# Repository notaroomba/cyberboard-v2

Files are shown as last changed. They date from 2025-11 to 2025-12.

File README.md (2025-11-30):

<h1 align="center">
  <br>
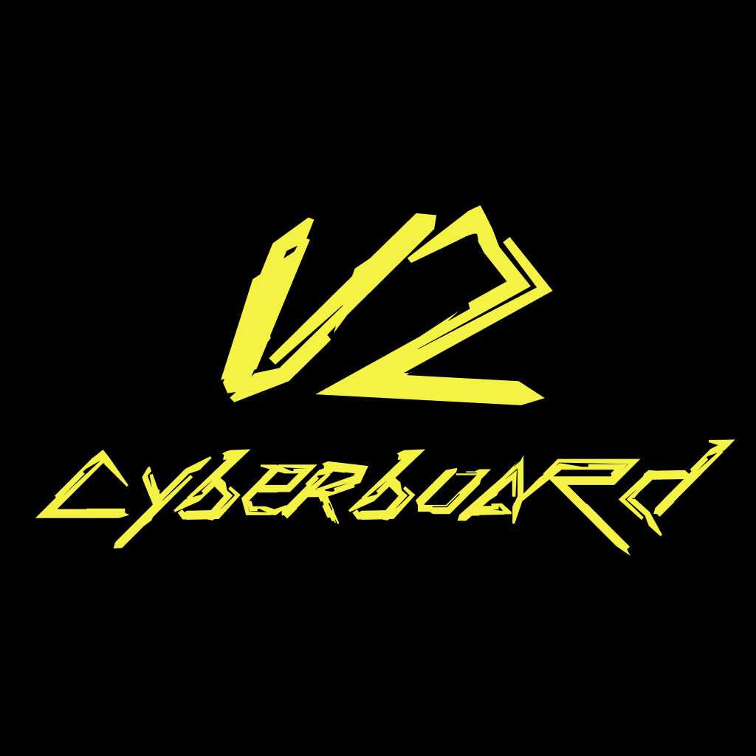
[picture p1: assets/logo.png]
Cyberboard V2
  
  <br>
  Cyberboard V2
  <br>
</h1>

<h4 align="center">
A Raspberry Pi Pico-sized STM32 development board with Bluetooth, battery support, IMU and a barometer!
</h4>

<div align="center">




</div>

<p align="center">
  <a href="#key-features">Key Features</a> •
  <a href="#pcb">PCB</a> •
  <a href="#credits">Credits</a> •
  <a href="#license">License</a>
</p>

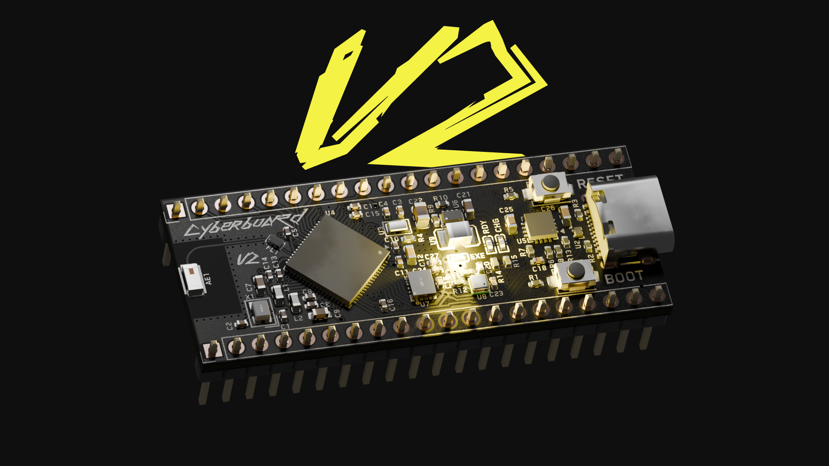
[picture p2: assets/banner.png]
Cyberboard Banner


## Key Features

- **STM32WB55CG** microcontroller with Bluetooth support
- **Raspberry Pi Pico form factor** for compatibility
- **IMU and Barometer** - ICM-42688 (6-axis) and BMP580 pressure sensor for environmental/motion sensing
- **Battery charging** with BQ24072RGTR IC and JST connector for 1S LiPo
- **Buck-Boost converter** (TPS631000) for efficient power management
- **Multiple Status LEDs** for visual feedback
- **USB-C** connectivity
- **Ceramic Bluetooth antenna** with impedance matching
- **SWD test points** on the bottom for easy programming
- **4-layer PCB** design with optimized RF layout and routing
- **Panelized design** for cost-effective manufacturing

## PCB

Designed in KiCad with attention to RF design, power management, and sensor integration. The board features a 4-layer stackup (SIG/GND/PWR/SIG) with optimized routing for the Bluetooth antenna and sensitive analog signals.

### Features

- Efficient antenna routing with impedance matching
- Optimized sensor placement (IMU and Barometer) away from RF components
- SPI interface for IMU (ICM-42688) and I2C interface for Barometer (BMP580)
- Improved power delivery with optimized buck-boost converter

### Schematic

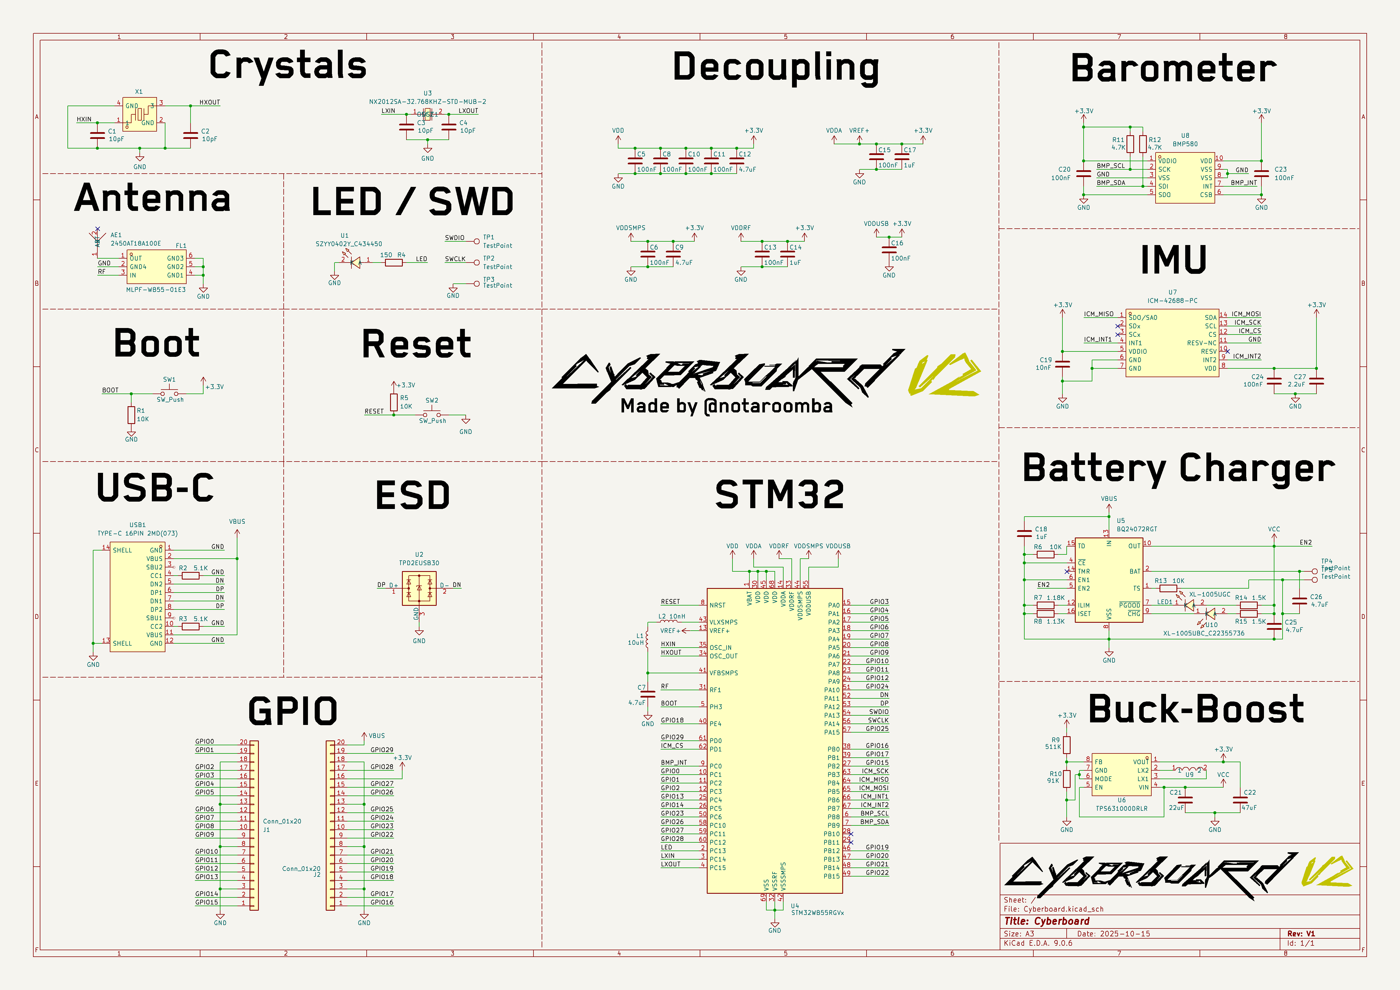
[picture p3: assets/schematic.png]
Schematic


### PCB Layers

The 4-layer stackup (SIG/GND/PWR/SIG) provides optimal signal integrity and power distribution:

**Layer 1 (Signal):**
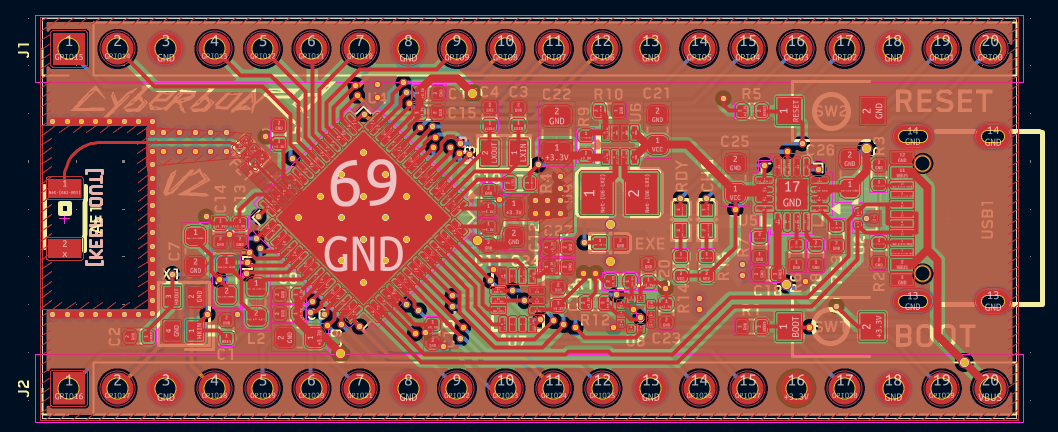
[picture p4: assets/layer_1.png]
PCB Layer 1


**Layer 2 (Ground):**
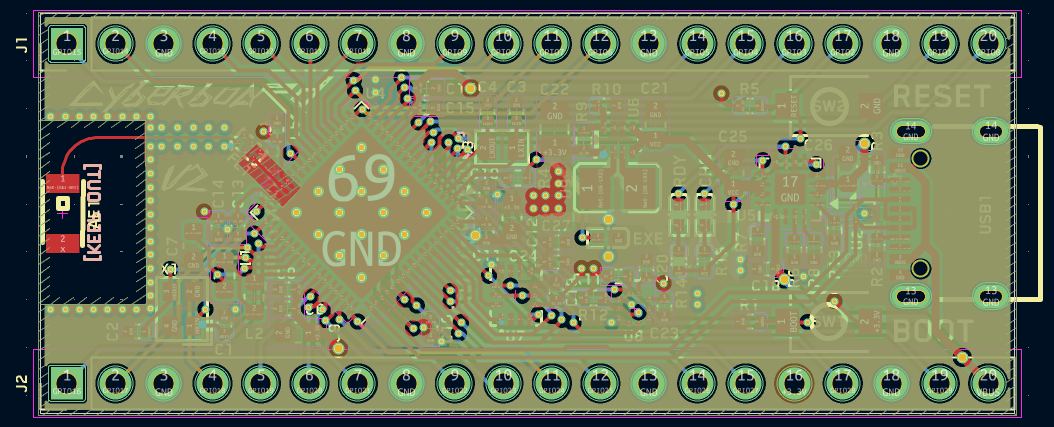
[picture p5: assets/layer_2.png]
PCB Layer 2


**Layer 3 (Power):**
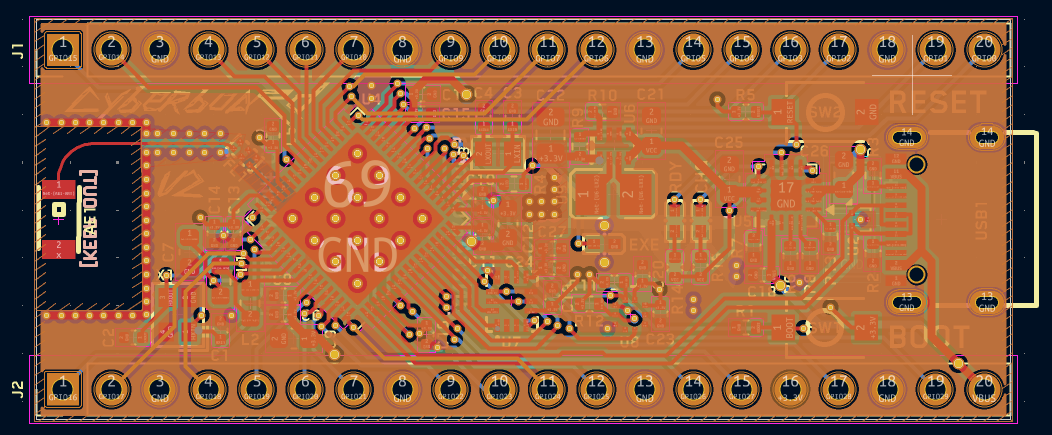
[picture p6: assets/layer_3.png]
PCB Layer 3


**Layer 4 (Signal):**
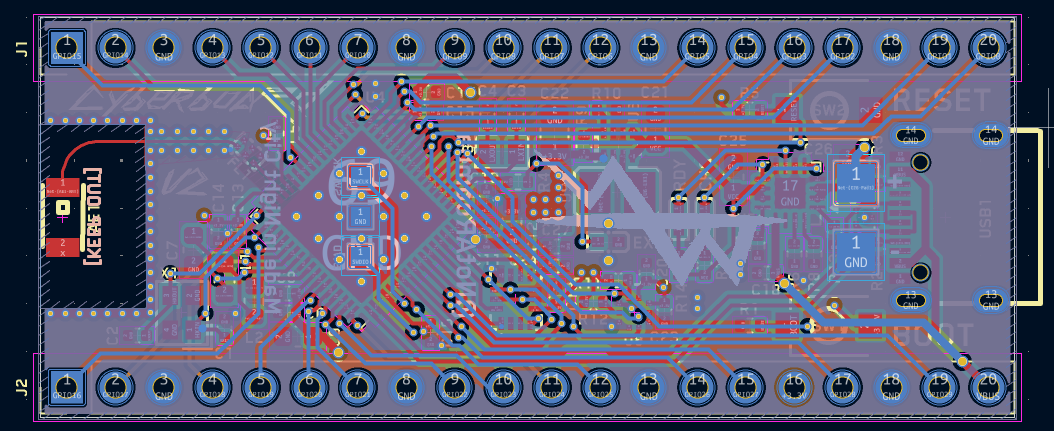
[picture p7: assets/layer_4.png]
PCB Layer 4


**Front:**
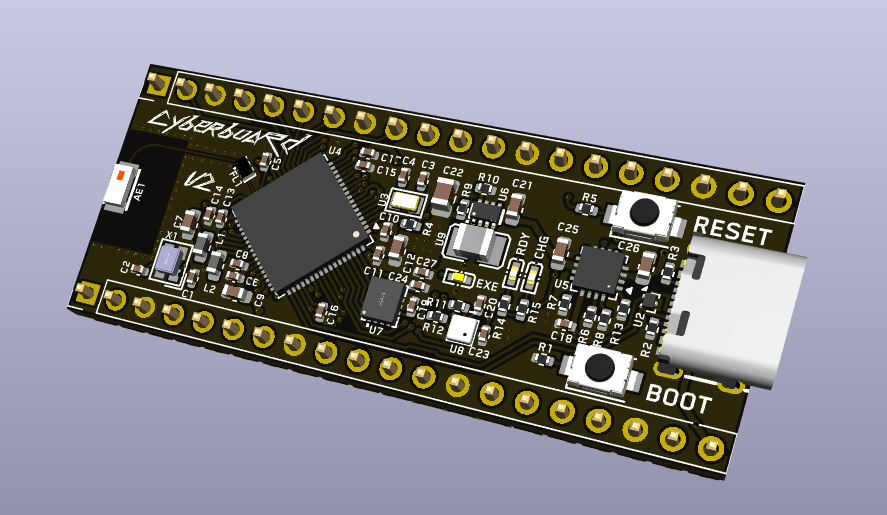
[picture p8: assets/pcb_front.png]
PCB Front


**Back:**
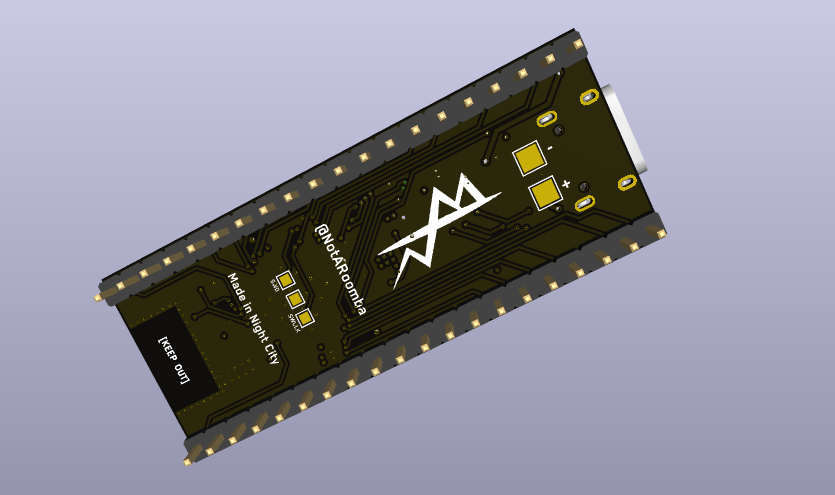
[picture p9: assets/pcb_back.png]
PCB Back


### JLCPCB Order

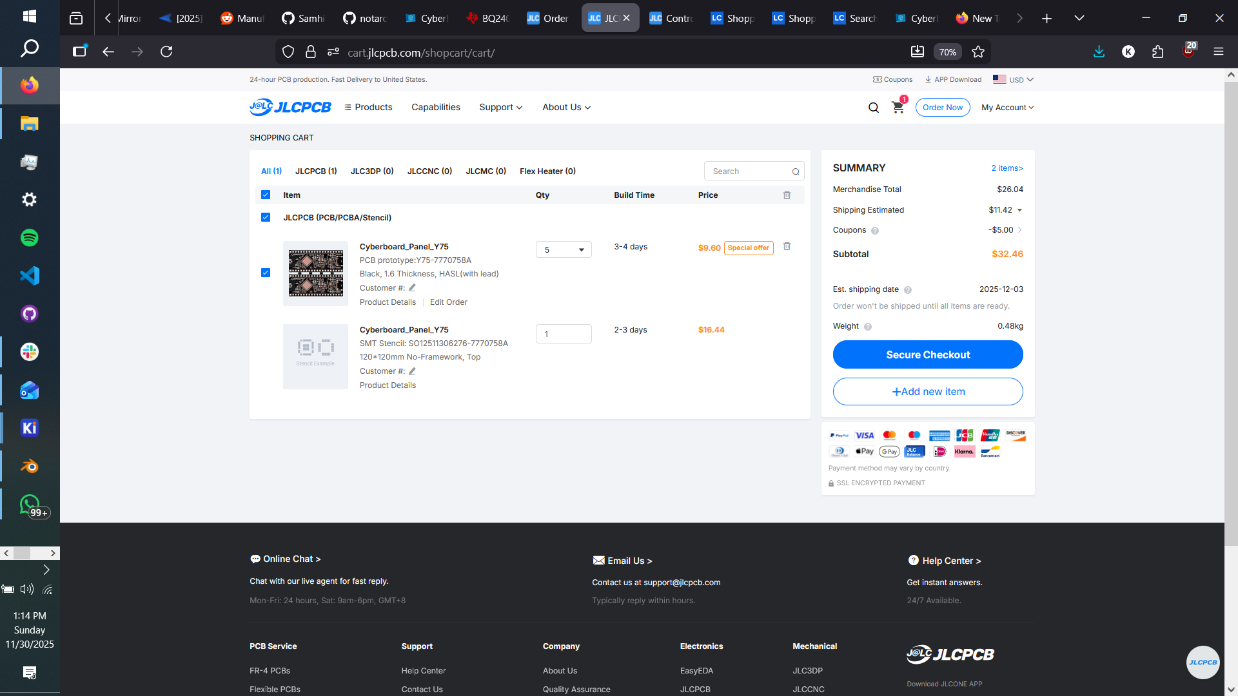
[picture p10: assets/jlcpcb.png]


## Credits

This project uses:

- [KiCad](https://www.kicad.org/)
- [Blender](https://www.blender.org/) for 3D renders
- [Hack Club Blueprint](https://blueprint.hackclub.com/projects/491)

## You may also like...

- [CyberCard](https://github.com/NotARoomba/CyberCard) – A Cyberpunk themed NFC hacker card
- [Niveles De Niveles](https://github.com/NotARoomba/NivelesDeNiveles) – Real-time flood alert app
- [Linea](https://github.com/NotARoomba/Linea) – An EMR tablet
- [Tamaki](https://github.com/NotARoomba/Tamaki) – A cute HackPad

## License

MIT

---

> [notaroomba.dev](https://notaroomba.dev) &nbsp;&middot;&nbsp;
> GitHub [@NotARoomba](https://github.com/NotARoomba) &nbsp;&middot;&nbsp;

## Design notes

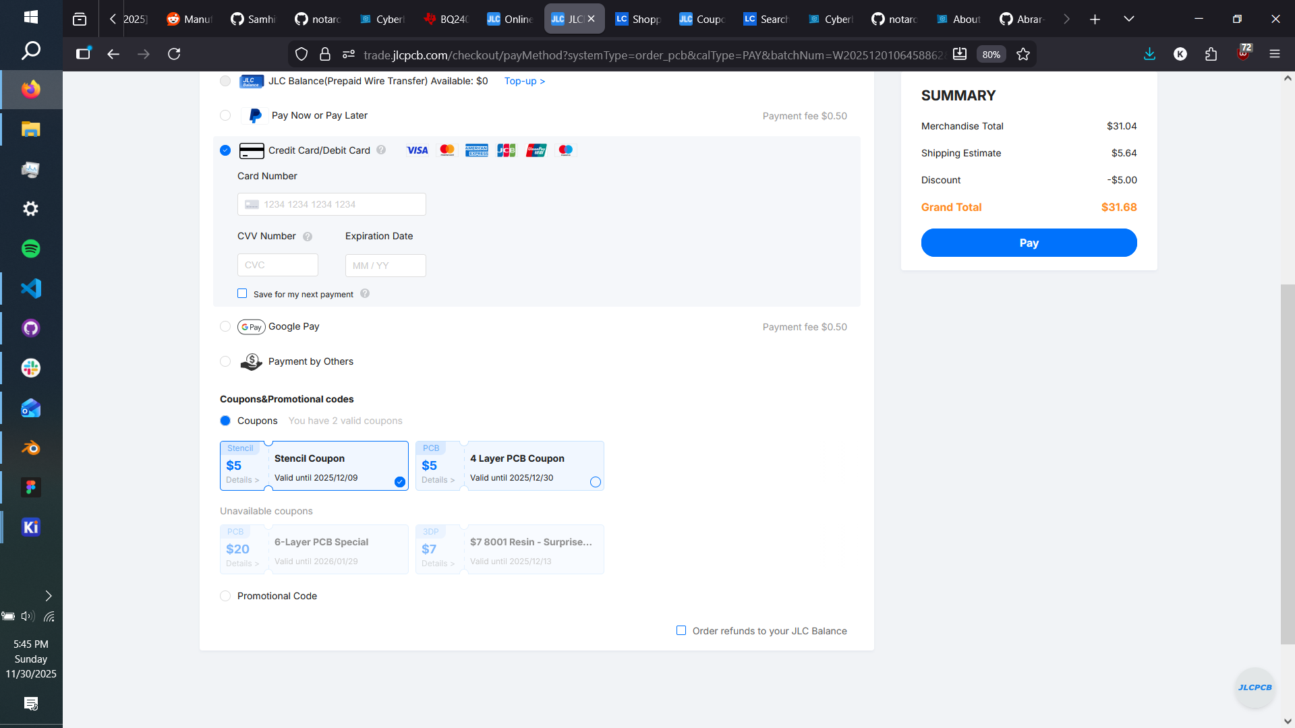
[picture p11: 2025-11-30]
assets/jlcpcb_2.png

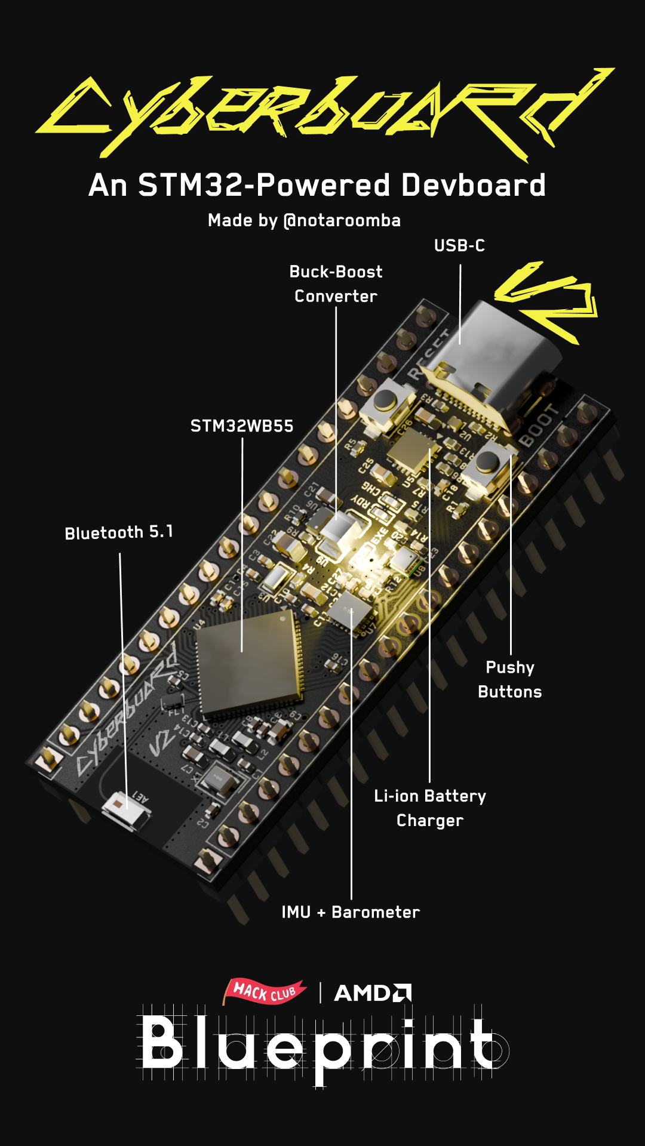
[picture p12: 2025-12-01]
assets/flyer.png

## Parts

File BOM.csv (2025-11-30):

Item | Cost | Source
PCB + Stencil | 31.68 | JLCPCB
Parts | 67.13 | LCSC
Total | 98.81 | ---

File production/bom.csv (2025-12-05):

Designator | Footprint | Quantity | Value | LCSC Part #
AE1 | ANT-SMD_L3.2-W1.6 | 1 | 2450AT18A100E | C89334
C1, C2, C3, C4 | 0402 | 4 | 10pF
C10, C11, C13, C15, C16, C20, C23, C24, C5, C6, C8 | 0402 | 11 | 100nF
C12, C25, C26, C7, C9 | 0603 | 5 | 4.7uF
C14, C17, C18 | 0402 | 3 | 1uF
C19 | 0402 | 1 | 10nF
C21 | 0603 | 1 | 22uF | C361061
C22 | 0805 | 1 | 47uF | C471380
C27 | 0402 | 1 | 2.2uF
FL1 | FILTER-SMD_6P-L1.6-W1.0-P0.50-BL | 1 | MLPF-WB55-01E3 | C2651048
J1, J2 | PinHeader_1x20_P2.54mm_Vertical | 2 | Conn_01x20 | C42431804
L1 | 0603 | 1 | 10uH
L2 | 0603 | 1 | 10nH
LED1 | LED0402-RD_GREEN | 1 | XL-1005UGC | C965793
R1, R13, R5, R6 | 0402 | 4 | 10K
R10 | 0402 | 1 | 91K
R11, R12, R16 | 0402 | 3 | 4.7K
R14, R15 | 0402 | 2 | 1.5K
R2, R3 | 0402 | 2 | 5.1K
R4 | 0402 | 1 | 150 | C25082
R7 | 0402 | 1 | 1.18K
R8 | 0402 | 1 | 1.13K
R9 | 0402 | 1 | 511K
SW1, SW2 | SW-SMD_L3.9-W3.0-P4.45 | 2 | SW_Push | C720477
U1 | LED0402-FD_YELLOW | 1 | SZYY0402Y_C434450 | C434450
U10 | LED0402-RD | 1 | XL-1005UBC_C22355736 | C22355736
U2 | Texas_DRT-3 | 1 | TPD2EUSB30
U3 | CRYSTAL-SMD_L2.0-W1.2 | 1 | NX2012SA-32.768KHZ-STD-MUB-2 | C891748
U4 | QFN-68-1EP_8x8mm_P0.4mm_EP6.4x6.4mm | 1 | STM32WB55RGVx | C401505
U5 | VQFN-16-1EP_3x3mm_P0.5mm_EP1.6x1.6mm | 1 | BQ24072RGT | C140288
U6 | SOT-583-8_L2.1-W1.2-P0.50-LS1.6-BL | 1 | TPS631000DRLR | C5219190
U7 | LGA-14_L3.0-W2.5-P0.50-TL | 1 | ICM-42688-PC | C48586483
U8 | LGA-10_L2.0-W2.0-P0.50-TL_BMP580 | 1 | BMP580 | C22391138
U9 | L1008 | 1 | DFE252012P-1R0M=P2 | C882955
USB1 | USB-C-SMD_TYPE-C-6PIN-2MD-073 | 1 | TYPE-C 16PIN 2MD(073) | C2765186
X1 | OSC-SMD_4P-L2.0-W1.6-BL | 1 | NX2016SA-32MHZ-STD-CZS-5 | C843260

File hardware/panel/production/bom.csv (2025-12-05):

Designator | Footprint | Quantity | Value | LCSC Part #
AE1_2, AE1 | ANT-SMD_L3.2-W1.6 | 2 | 2450AT18A100E | C89334
C1_2, C1, C2_2, C2, C3_2, C3, C4_2, C4 | 0402 | 8 | 10pF
C10_2, C10, C11_2, C11, C13_2, C13, C15_2, C15, C16_2, C16, C20_2, C20, C23_2, C23, C24_2, C24, C5_2, C5, C6_2, C6, C8_2, C8 | 0402 | 22 | 100nF
C12_2, C12, C25_2, C25, C26_2, C26, C7_2, C7, C9_2, C9 | 0603 | 10 | 4.7uF
C14_2, C14, C17_2, C17, C18_2, C18 | 0402 | 6 | 1uF
C19_2, C19 | 0402 | 2 | 10nF
C21_2, C21 | 0603 | 2 | 22uF | C361061
C22_2, C22 | 0805 | 2 | 47uF | C471380
C27_2, C27 | 0402 | 2 | 2.2uF
FL1_2, FL1 | FILTER-SMD_6P-L1.6-W1.0-P0.50-BL | 2 | MLPF-WB55-01E3 | C2651048
J1_2, J1, J2_2, J2 | PinHeader_1x20_P2.54mm_Vertical | 4 | Conn_01x20 | C42431804
L1_2, L1 | 0603 | 2 | 10uH
L2_2, L2 | 0603 | 2 | 10nH
LED1_2, LED1 | LED0402-RD_GREEN | 2 | XL-1005UGC | C965793
R1_2, R1, R13_2, R13, R5_2, R5, R6_2, R6 | 0402 | 8 | 10K
R10_2, R10 | 0402 | 2 | 91K
R11_2, R11, R12_2, R12, R16_2, R16 | 0402 | 6 | 4.7K
R14_2, R14, R15_2, R15 | 0402 | 4 | 1.5K
R2_2, R2, R3_2, R3 | 0402 | 4 | 5.1K
R4_2, R4 | 0402 | 2 | 150 | C25082
R7_2, R7 | 0402 | 2 | 1.18K
R8_2, R8 | 0402 | 2 | 1.13K
R9_2, R9 | 0402 | 2 | 511K
SW1_2, SW1, SW2_2, SW2 | SW-SMD_L3.9-W3.0-P4.45 | 4 | SW_Push | C720477
U1_2, U1 | LED0402-FD_YELLOW | 2 | SZYY0402Y_C434450 | C434450
U10_2, U10 | LED0402-RD | 2 | XL-1005UBC_C22355736 | C22355736
U2_2, U2 | Texas_DRT-3 | 2 | TPD2EUSB30
U3_2, U3 | CRYSTAL-SMD_L2.0-W1.2 | 2 | NX2012SA-32.768KHZ-STD-MUB-2 | C891748
U4_2, U4 | QFN-68-1EP_8x8mm_P0.4mm_EP6.4x6.4mm | 2 | STM32WB55RGVx | C401505
U5_2, U5 | VQFN-16-1EP_3x3mm_P0.5mm_EP1.6x1.6mm | 2 | BQ24072RGT | C140288
U6_2, U6 | SOT-583-8_L2.1-W1.2-P0.50-LS1.6-BL | 2 | TPS631000DRLR | C5219190
U7_2, U7 | LGA-14_L3.0-W2.5-P0.50-TL | 2 | ICM-42688-PC | C48586483
U8_2, U8 | LGA-10_L2.0-W2.0-P0.50-TL_BMP580 | 2 | BMP580 | C22391138
U9_2, U9 | L1008 | 2 | DFE252012P-1R0M=P2 | C882955
USB1_2, USB1 | USB-C-SMD_TYPE-C-6PIN-2MD-073 | 2 | TYPE-C 16PIN 2MD(073) | C2765186
X1_2, X1 | OSC-SMD_4P-L2.0-W1.6-BL | 2 | NX2016SA-32MHZ-STD-CZS-5 | C843260

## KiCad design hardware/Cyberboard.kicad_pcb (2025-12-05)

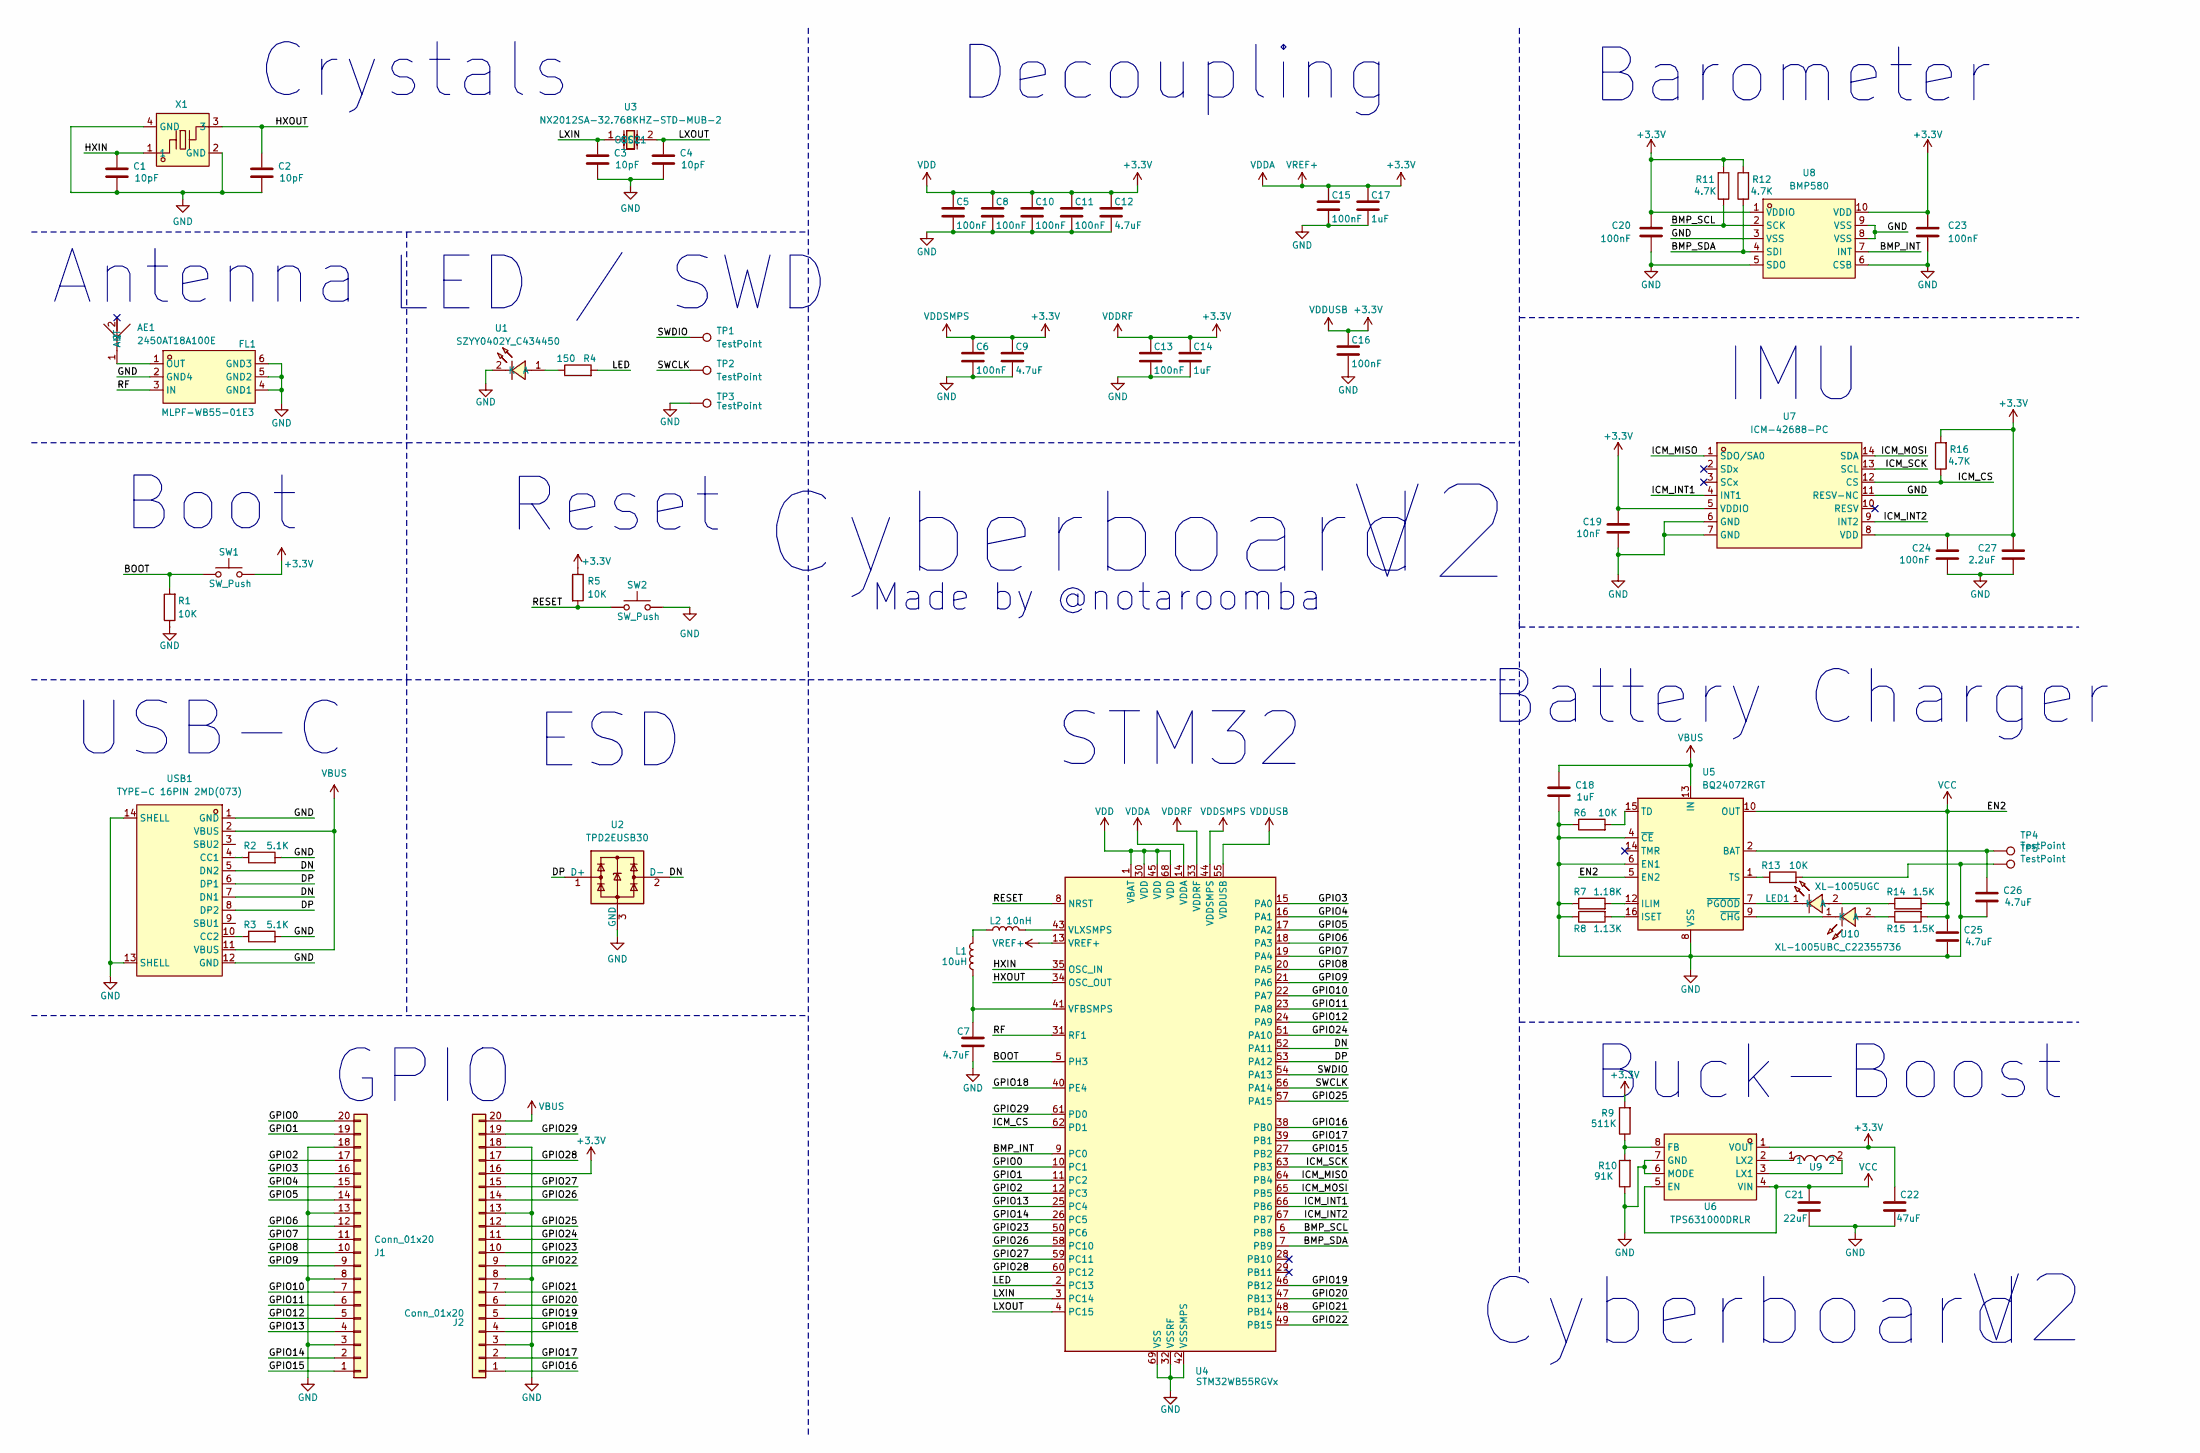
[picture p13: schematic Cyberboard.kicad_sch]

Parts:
AE1: 2450AT18A100E; ANT-SMD_L3.2-W1.6; LCSC Part C89334
C1, C2, C3, C4: 10pF; C_0402_1005Metric
C5, C6, C8, C10, C11, C13, C15, C16, C20, C23, C24: 100nF; C_0402_1005Metric
C7, C9, C12, C25, C26: 4.7uF; C_0603_1608Metric
C14, C17, C18: 1uF; C_0402_1005Metric
C19: 10nF; C_0402_1005Metric
C21: 22uF; C_0603_1608Metric; LCSC C361061
C22: 47uF; C_0805_2012Metric; LCSC C471380
C27: 2.2uF; C_0402_1005Metric
FL1: MLPF-WB55-01E3; FILTER-SMD_6P-L1.6-W1.0-P0.50-BL; LCSC Part C2651048
J1, J2: Conn_01x20; PinHeader_1x20_P2.54mm_Vertical; LCSC C42431804
L1: 10uH; L_0603_1608Metric
L2: 10nH; L_0603_1608Metric
LED1: XL-1005UGC; LED0402-RD_GREEN; LCSC Part C965793
R1, R5, R6, R13: 10K; R_0402_1005Metric
R2, R3: 5.1K; R_0402_1005Metric
R4: 150; R_0402_1005Metric; LCSC C25082
R7: 1.18K; R_0402_1005Metric
R8: 1.13K; R_0402_1005Metric
R9: 511K; R_0402_1005Metric
R10: 91K; R_0402_1005Metric
R11, R12, R16: 4.7K; R_0402_1005Metric
R14, R15: 1.5K; R_0402_1005Metric
SW1, SW2: SW_Push; SW-SMD_L3.9-W3.0-P4.45; LCSC C720477
TP1, TP2, TP3: TestPoint; TestPoint_Pad_1.0x1.0mm
TP4, TP5: TestPoint; TestPoint_Pad_2.0x2.0mm
U1: SZYY0402Y_C434450; LED0402-FD_YELLOW; LCSC Part C434450
U2: TPD2EUSB30; Texas_DRT-3
U3: NX2012SA-32.768KHZ-STD-MUB-2; CRYSTAL-SMD_L2.0-W1.2; LCSC Part C891748
U4: STM32WB55RGVx; QFN-68-1EP_8x8mm_P0.4mm_EP6.4x6.4mm; LCSC C401505
U5: BQ24072RGT; VQFN-16-1EP_3x3mm_P0.5mm_EP1.6x1.6mm; LCSC C140288
U6: TPS631000DRLR; SOT-583-8_L2.1-W1.2-P0.50-LS1.6-BL; LCSC Part C5219190
U7: ICM-42688-PC; LGA-14_L3.0-W2.5-P0.50-TL; LCSC Part C48586483
U8: BMP580; LGA-10_L2.0-W2.0-P0.50-TL_BMP580; LCSC Part C22391138
U9: DFE252012P-1R0M=P2; L1008; LCSC Part C882955
U10: XL-1005UBC_C22355736; LED0402-RD; LCSC Part C22355736
USB1: TYPE-C 16PIN 2MD(073); USB-C-SMD_TYPE-C-6PIN-2MD-073; LCSC Part C2765186
X1: NX2016SA-32MHZ-STD-CZS-5; OSC-SMD_4P-L2.0-W1.6-BL; LCSC Part C843260

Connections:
+3.3V: C5.1, C6.1, C8.1, C9.1, C10.1, C11.1, C12.1, C13.1, C14.1, C15.1, C16.1, C17.1, C19.1, C20.1, C22.1, C23.1, C24.1, C27.1, J2.16, R5.1, R9.2, R11.2, R12.2, R16.2, SW1.2, U4.1 (VBAT), U4.13 (VREF+), U4.14 (VDDA), U4.30 (VDD), U4.33 (VDDRF), U4.44 (VDDSMPS), U4.45 (VDD), U4.55 (VDDUSB), U4.68 (VDD), U6.1 (VOUT), U7.5 (VDDIO), U7.8 (VDD), U8.1 (VDDIO), U8.10 (VDD)
/BMP_INT: U4.9 (PC0), U8.7 (INT)
/BMP_SCL: R11.1, U4.6 (PB8), U8.2 (SCK)
/BMP_SDA: R12.1, U4.7 (PB9), U8.4 (SDI)
/BOOT: R1.2, SW1.1, U4.5 (PH3)
/DN: U2.2 (D-), U4.52 (PA11), USB1.5 (DN2), USB1.7 (DN1)
/DP: U2.1 (D+), U4.53 (PA12), USB1.6 (DP1), USB1.8 (DP2)
/GPIO0: J1.20, U4.10 (PC1)
/GPIO1: J1.19, U4.11 (PC2)
/GPIO2: J1.17, U4.12 (PC3)
/GPIO3: J1.16, U4.15 (PA0)
/GPIO4: J1.15, U4.16 (PA1)
/GPIO5: J1.14, U4.17 (PA2)
/GPIO6: J1.12, U4.18 (PA3)
/GPIO7: J1.11, U4.19 (PA4)
/GPIO8: J1.10, U4.20 (PA5)
/GPIO9: J1.9, U4.21 (PA6)
/GPIO10: J1.7, U4.22 (PA7)
/GPIO11: J1.6, U4.23 (PA8)
/GPIO12: J1.5, U4.24 (PA9)
/GPIO13: J1.4, U4.25 (PC4)
/GPIO14: J1.2, U4.26 (PC5)
/GPIO15: J1.1, U4.27 (PB2)
/GPIO16: J2.1, U4.38 (PB0)
/GPIO17: J2.2, U4.39 (PB1)
/GPIO18: J2.4, U4.40 (PE4)
/GPIO19: J2.5, U4.46 (PB12)
/GPIO20: J2.6, U4.47 (PB13)
/GPIO21: J2.7, U4.48 (PB14)
/GPIO22: J2.9, U4.49 (PB15)
/GPIO23: J2.10, U4.50 (PC6)
/GPIO24: J2.11, U4.51 (PA10)
/GPIO25: J2.12, U4.57 (PA15)
/GPIO26: J2.14, U4.58 (PC10)
/GPIO27: J2.15, U4.59 (PC11)
/GPIO28: J2.17, U4.60 (PC12)
/GPIO29: J2.19, U4.61 (PD0)
/HXIN: C1.1, U4.35 (OSC_IN), X1.1
/HXOUT: C2.1, U4.34 (OSC_OUT), X1.3
/ICM_CS: R16.1, U4.62 (PD1), U7.12 (CS)
/ICM_INT1: U4.66 (PB6), U7.4 (INT1)
/ICM_INT2: U4.67 (PB7), U7.9 (INT2)
/ICM_MISO: U4.64 (PB4), U7.1 (SDO/SA0)
/ICM_MOSI: U4.65 (PB5), U7.14 (SDA)
/ICM_SCK: U4.63 (PB3), U7.13 (SCL)
/LED: R4.2, U4.2 (PC13)
/LXIN: C3.1, U3.1 (OSC1), U4.3 (PC14)
/LXOUT: C4.1, U3.2 (OSC2), U4.4 (PC15)
/RESET: R5.2, SW2.1, U4.8 (NRST)
/RF: FL1.3 (IN), U4.31 (RF1)
/SWCLK: TP2.1, U4.56 (PA14)
/SWDIO: TP1.1, U4.54 (PA13)
GND: C1.2, C2.2, C3.2, C4.2, C5.2, C6.2, C7.2, C8.2, C9.2, C10.2, C11.2, C12.2, C13.2, C14.2, C15.2, C16.2, C17.2, C18.2, C19.2, C20.2, C21.2, C22.2, C23.2, C24.2, C25.2, C26.2, C27.2, FL1.2 (GND4), FL1.4 (GND1), FL1.5 (GND2), FL1.6 (GND3), J1.3, J1.8, J1.13, J1.18, J2.3, J2.8, J2.13, J2.18, R1.1, R2.2, R3.2, R6.1, R7.1, R8.1, R10.1, R13.2, SW2.2, TP3.1, TP5.1, U1.2 (K), U2.3 (GND), U4.32 (VSSRF), U4.42 (VSSSMPS), U4.69 (VSS), U5.4 (~CE), U5.6 (EN1), U5.8 (VSS), U5.17 (VSS), U6.6 (MODE), U6.7 (GND), U7.6 (GND), U7.7 (GND), U7.11 (RESV-NC), U8.3 (VSS), U8.5 (SDO), U8.6 (CSB), U8.8 (VSS), U8.9 (VSS), USB1.1 (GND), USB1.12 (GND), USB1.13 (SHELL), USB1.14 (SHELL), X1.2 (GND), X1.4 (GND)
unnamed: AE1.1 (ANT), FL1.1 (OUT)
unnamed: C26.1, TP4.1, U5.2 (BAT), U5.3 (BAT)
unnamed: L1.1, L2.2
unnamed: LED1.2 (A), R14.1
unnamed: LED1.1 (K), U5.7 (~PGOOD)
unnamed: R4.1, U1.1 (A)
unnamed: C7.1, L1.2, U4.41 (VFBSMPS)
unnamed: L2.1, U4.43 (VLXSMPS)
unnamed: R7.2, U5.12 (ILIM)
unnamed: R8.2, U5.16 (ISET)
unnamed: R6.2, U5.15 (TD)
unnamed: R13.1, U5.1 (TS)
unnamed: R9.1, R10.2, U6.8 (FB)
unnamed: U6.3 (LX1), U9.2
unnamed: U6.2 (LX2), U9.1
unnamed: R15.1, U10.2 (A)
unnamed: U5.9 (~CHG), U10.1 (K)
unnamed: R2.1, USB1.4 (CC1)
unnamed: R3.1, USB1.10 (CC2)
VBUS: C18.1, J2.20, U5.13 (IN), USB1.2 (VBUS), USB1.11 (VBUS)
VCC: C21.1, C25.1, R14.2, R15.2, U5.5 (EN2), U5.10 (OUT), U5.11 (OUT), U6.4 (VIN), U6.5 (EN)

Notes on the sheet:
Cyberboard
Decoupling
IMU
Made by @notaroomba
Reset
LED / SWD
Antenna
STM32
ESD
Battery Charger
Boot
USB-C
Buck-Boost
Barometer
GPIO
Crystals

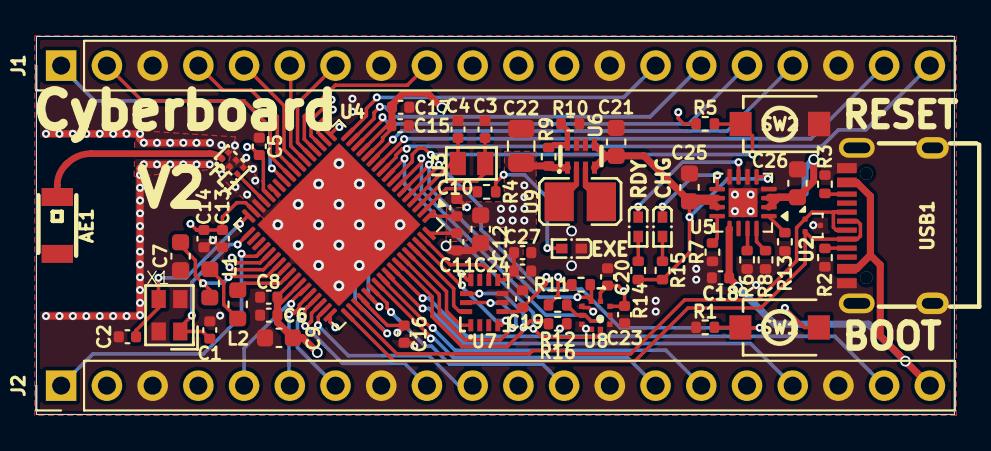
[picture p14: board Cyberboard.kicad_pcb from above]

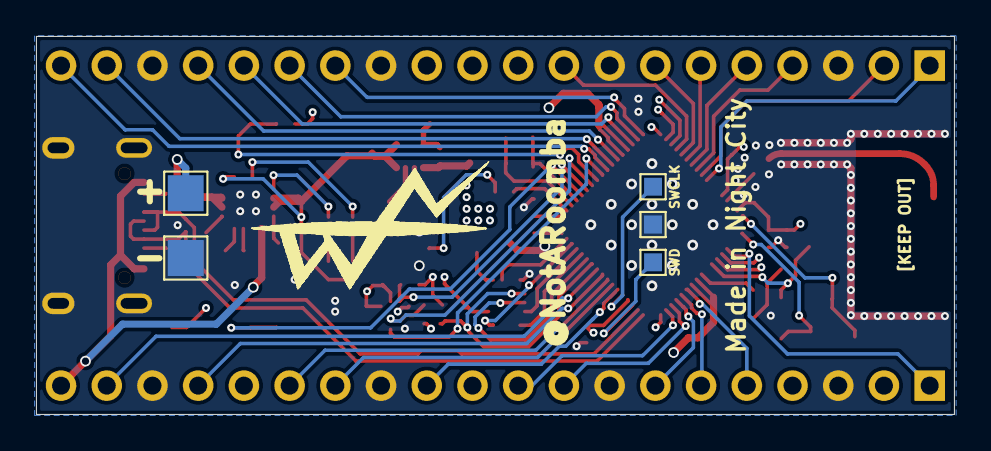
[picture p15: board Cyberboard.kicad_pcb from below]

Board: 4 copper layers, 51.0 x 21.0 mm, 69 parts (5 on the bottom side), 74 nets.

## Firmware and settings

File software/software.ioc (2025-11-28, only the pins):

Mcu.UserName=STM32WB55RGVx
PA11.Signal=USB_DM
PA12.Signal=USB_DP
PB3.GPIO_Label=ICM_SCK
PB3.Signal=SPI1_SCK
PB4.GPIO_Label=ICM_MISO
PB4.Signal=SPI1_MISO
PB5.GPIO_Label=ICM_MOSI
PB5.Signal=SPI1_MOSI
PB6.GPIO_Label=ICM_INT2
PB6.Signal=GPXTI6
PB7.GPIO_Label=ICM_INT1
PB7.Signal=GPXTI7
PB8.GPIO_Label=BMP_SCL
PB8.Signal=I2C1_SCL
PB9.GPIO_Label=BMP_SDA
PB9.Signal=I2C1_SDA
PC0.GPIO_Label=BMP_INT
PC0.Signal=GPXTI0
PC13.GPIO_Label=ICM_CS
PC13.Signal=GPIO_Output
PC14-OSC32_IN.Signal=RCC_OSC32_IN
PC15-OSC32_OUT.Signal=RCC_OSC32_OUT
PD1.GPIO_Label=LED
PD1.Signal=GPIO_Output

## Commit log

2025-11-29 started PCB
    [Cyberboard.kicad_pcb, Cyberboard.kicad_sch]
2025-11-30 start routing
    [Cyberboard.kicad_pcb, Cyberboard.kicad_sch]
2025-11-30 finish routing and antenna
    [Cyberboard.kicad_pcb]
2025-11-30 add stuff
    [Cyberboard.kicad_pcb, Cyberboard.kicad_sch, Cyberboard_Panel.kicad_pcb]
2025-11-30 add in csvs
    [BOM.csv, bom.csv, designators.csv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]
2025-11-30 update bom
    [BOM.csv]
2025-12-01 rounded corners and new renders and flyer
    [Cyberboard.kicad_pcb, Cyberboard_Panel.kicad_pcb, bom.csv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]
2025-12-05 final final bluetooth trace udpate
    [Cyberboard.kicad_pcb, Cyberboard.kicad_sch, Cyberboard_Panel.kicad_pcb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]
